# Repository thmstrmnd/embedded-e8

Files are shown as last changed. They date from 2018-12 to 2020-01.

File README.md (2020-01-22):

## Embedded E8

**An open source IoT hardware integration project that extends the capabilities of ESP8266 with components that are readily available in the market. As a result, fast prototyping and independent development is achieved.**

## Table of Contents
1. [Mission](#mission)
2. [General](#general) 
3. [Development Principles](#devprinciples)
4. [Bill of Materials](#bom)
5. [Software Tools](#tools)
6. [Connection Diagram](#connection)
7. [Microcontroller Setup and Code Upload](#setup)
8. [Final Assembly and Quick Reference](#final)
9. [Get Started](#start)
10. [Fork, Clone, then Contribute](#fork-clone-contribute)
11. [License](#license)

## Mission 

The mission of this project is to be a gateway of IoT education for the young, enthusiasts or professionals and to accelerate adoption of the IoT technology in the Philippines in private and business sectors to improve productivity.

## General 

ESP8266 is an impressive microcontroller because of its low cost and small form factor making IoT truly possible to be democratized. However, there are two major challenges of using ESP8266. The first one is lack of analog to digital (ADC) pins, hence by default only one sensor can be used. The second one is it's base voltage 3.3 Volts is not enough to trigger relays. Though there are sensors and relays that are rated 3.3V, they are not commonly available in the market. The most common ones are rated 5V. It is the intention of this project to solve these problems consolidate it into one integrated solution. 

We will also focus on a comprehensive documentation so that majority of the users will easily comprehend the technical aspects. This documentation is expected to be updated frequently. 

There will be 2 types of build. First, the breadboard version and second, the prototyping PCB version. Take note that we will not design nor etch a PCB board. 

The sequel of this project is called Cloud-E8 where you can now hook this up on the web. You can track your sensor data realtime, control your devices in the field and save these data on a database. 

## Development Principles 

Three main principles of this build: 
1. Easy to understand
2. Modular build
3. Affordable costs 

With these three development principles, the barrier to entry will drop. 

The build is modularized into 4 parts:
1. The microcontroller and the safety bus
2. The 5v-3.3V input/output pins
3. The Analog Pins for sensors 
4. The digital outputs and PWMs 

## Bill of Materials 

### For Breadboard Setup

1. WeMos D1 Mini | Qty 1 | https://wiki.wemos.cc/products:d1:d1_mini
2. Multiplexer | Qty 1 | https://learn.sparkfun.com/tutorials/multiplexer-breakout-hookup-guide
3. Level Converter | Qty 1 | https://learn.sparkfun.com/tutorials/bi-directional-logic-level-converter-hookup-guide
4. ULN2003 or ULN2004APG | Qty 1 | https://www.mouser.com/ds/2/408/ULN2004APG_datasheet_en_20101203-1135705.pdf
5. Half-sized Breadboard | Qty 3 | 
6. 1N4001 Diode | Qty 9 |  
7. Terminal Blocks | Qty 7 Pairs |

All these components are available locally. You can buy them in Lazada as well. 

## Software Tools 
1. Arduino IDE (Free) - for writing and uploading ESP codes
2. DraftSight (Free) - for drawing schematics
3. Linux Mint (Free) - desktop OS

## Connection Diagram 
Now you can start wiring components. Follow this [link](https://github.com/IoTPH/Assembly-E8/tree/master/ConnectionDiagram) for your guide. 

## Microcontroller Setup and Code Upload 
1. Download Arduino IDE: https://www.arduino.cc/en/Main/Software
2. Open the IDE and click: File -> Preferences -> Additional Boards Manager --> Paste this link: https://arduino.esp8266.com/stable/package_esp8266com_index.json
3. Then click: Tools -> Board -> Board Manager -> search ESP8266 Community, then click install
4. Then click again the Tools -> Board -> NodeMCU 1.0 (ESP12E Module)
5. Then click again the Tools -> PORT -> USB0 (or anything that works)
6. The click Sketch -> Upload | Note: This procedure uploads the bare minimum code and checks whether there are potential errors. There are two common errors. The first one is on the PORT setting. Go back to Tools -> PORT then choose the right one. The second one is the admin permission error. For linux users, run this command in your terminal to change the permission: $ sudo chown user path. Where "user" is your machine's username and path is the location of the permission denied folder.
7. At this point, you can now start building your projects and prototypes. Here are the sample code [sketches](https://github.com/IoTPH/Assembly-E8/tree/master/WorkableCodeSketches). 

## Final Assembly and Quick Reference 

### Connection Diagram
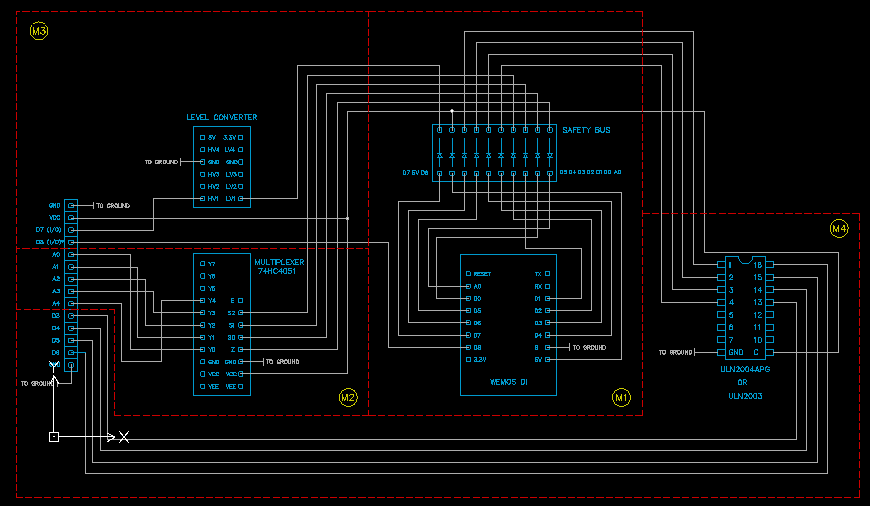
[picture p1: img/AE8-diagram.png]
Connection Diagram


### Breadboard Layout
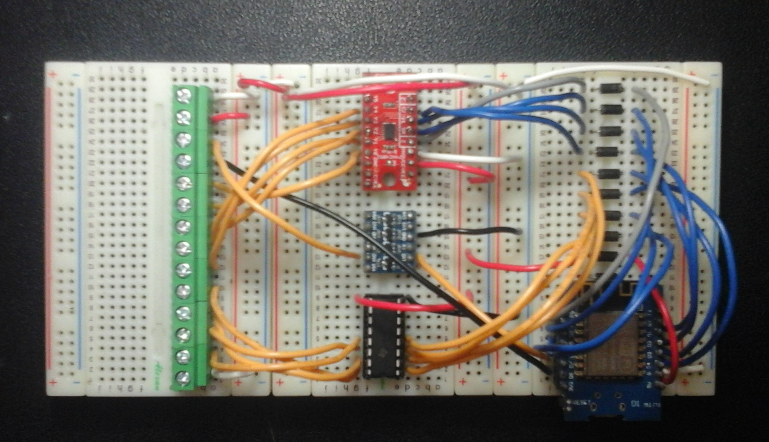
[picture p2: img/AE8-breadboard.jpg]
Breadboard Layout


## Get Started 

#### M1: ESP8266 Module 
* Upload the bare minimum code from the Arduino IDE. If there are errors, check whether you have chosen the right port, have admin access or have properly configured the Arduino IDE for ESP8266. 

#### M2: Multiplexer Module
* The multiplexer extends the analog to digital conversion (ADC) to 5. Hence, you can place up to 5 analog sensors simultaneously. Upload the code [ADConversion.ino](https://github.com/IoTPH/Assembly-E8/tree/master/WorkableCodeSketches) to ESP8266. Connect at least 2 analog sensors, then fire up the serial monitor and check whether it reads the values.

#### M3: Level Conversion Module
* Hookup an ultrasonic sensor HC-SR04 with its supply terminals across VCC and GND while its trigger pin at D7 (voltage level converted) and the echo pin is at D8. Upload the code [UltrasonicSensor.ino](https://github.com/IoTPH/Assembly-E8/tree/master/WorkableCodeSketches) to ESP8266. Fire up the serial monitor and check whether it reads the values.

#### M4: Transistor Array Module
* Connect a relay with its terminal at VCC and GND while its trigger leg at D3, D4, D5 or D6 pins. Upload the code [DigitalOutput.ino](https://github.com/IoTPH/Assembly-E8/tree/master/WorkableCodeSketches) to ESP8266. Check if it triggers the relay.

## Fork, Clone, then Contribute 

This project needs your help. You can voluntarily help us improve the design of the software and hardware. In order for you to do that, you need to do the following:  

### Fork  
You need to *fork* -- create a copy, this repository in your personal GitHub account.  

### Clone
Then, you need to *clone* -- create a local copy, it into your machine.  

### Contribute
Finally, you can start *hacking* -- , it and eventually create a pull request.  

## License: <a id="license"> MIT</a>

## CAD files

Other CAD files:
ConnectionDiagram/AE8.dwg

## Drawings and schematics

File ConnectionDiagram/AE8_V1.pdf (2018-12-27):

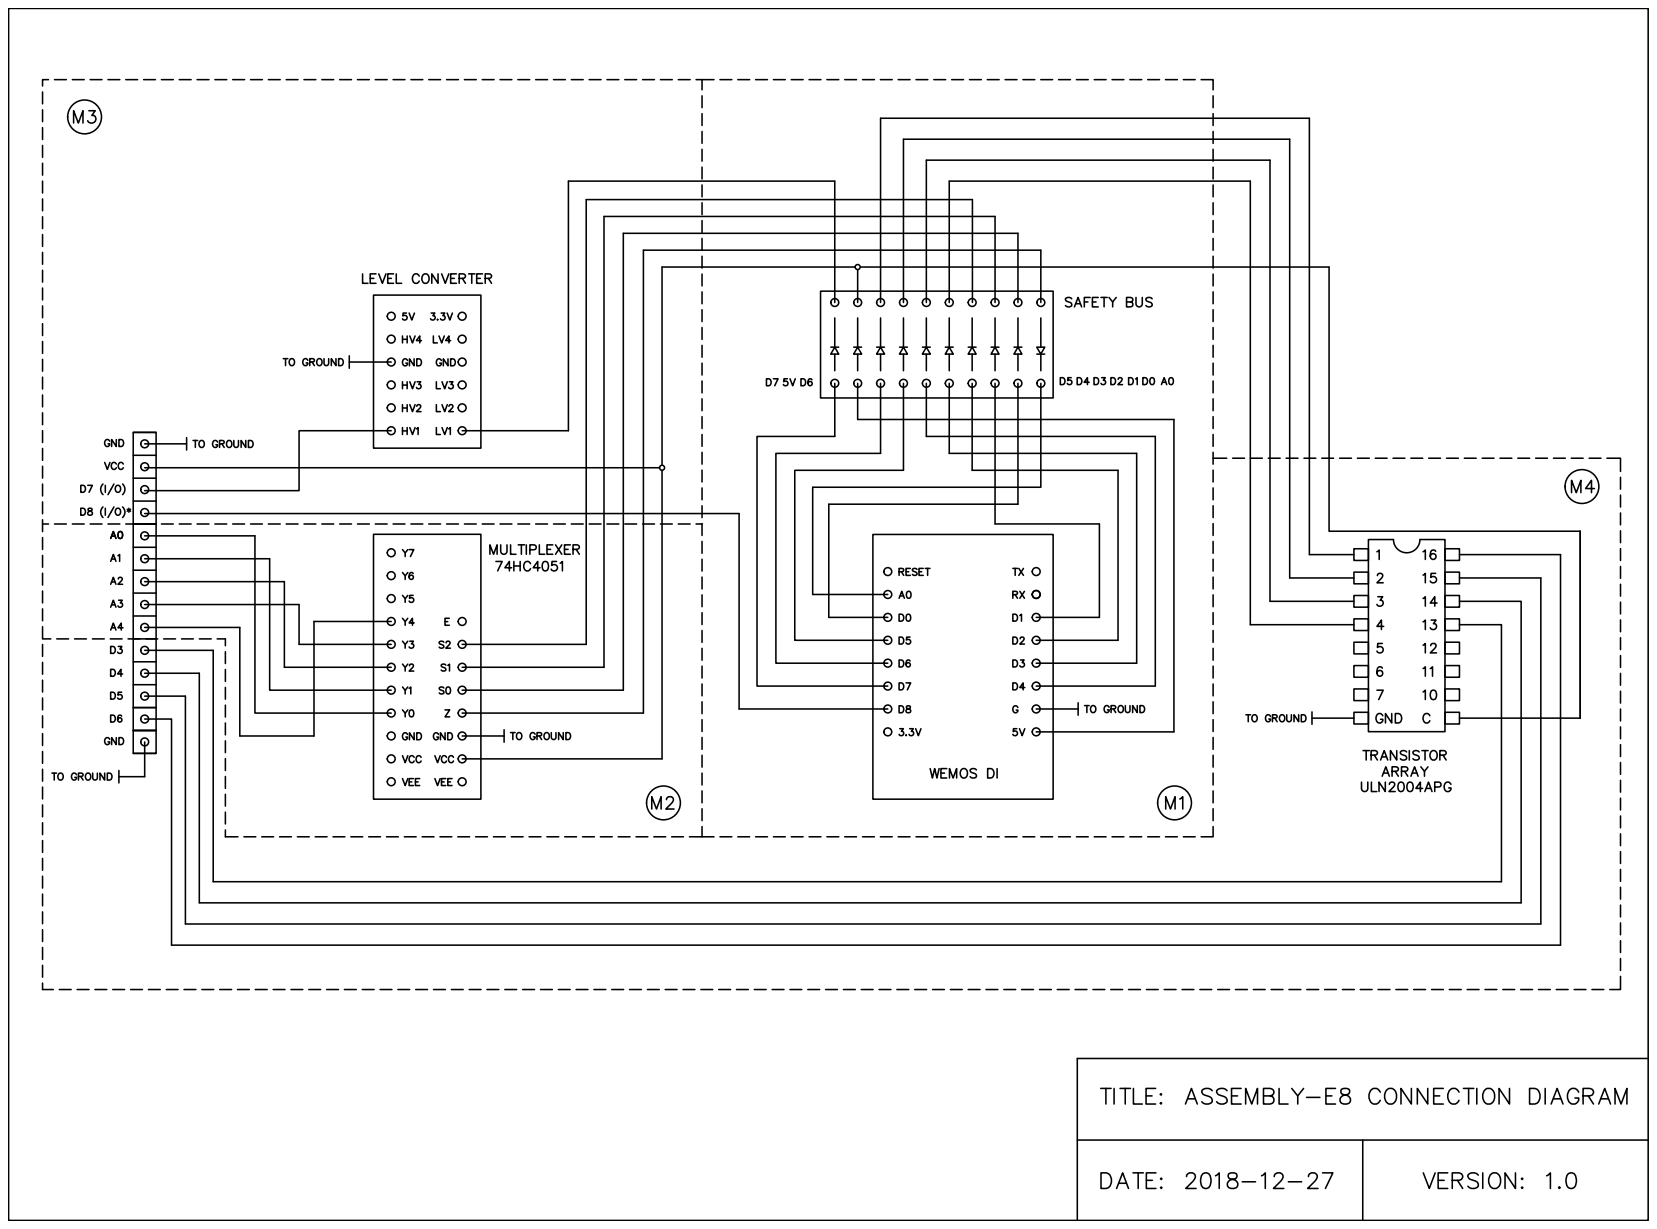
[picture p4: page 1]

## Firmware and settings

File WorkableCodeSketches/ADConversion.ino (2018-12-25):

/* 5 ANALOG SENSORS */
 
int pinOut00 = D0;
int pinOut01 = D1;
int pinOut02 = D2;
int pinOut03 = D3;
int pinOut04 = D4;

int pinInA0 = A0;
int valueInA0 = 0;
int valueInA1 = 0;
int valueInA2 = 0;
int valueInA3 = 0;
int valueInA4 = 0;

void setup() {                
  Serial.begin(9600);
  
  pinMode(pinOut00, OUTPUT);                    
  pinMode(pinOut01, OUTPUT);                    
  pinMode(pinOut02, OUTPUT);
  pinMode(pinOut03, OUTPUT);
  pinMode(pinOut04, OUTPUT);
  pinMode(pinOut05, OUTPUT);
  
  pinMode(pinInA0, INPUT);                      // Setting analog pin A0 to input    
}

void loop() {
  
  digitalWrite(pinOut04, HIGH);                  // Power Indicator
  delay(1000);                                   // Stabilizer

  digitalWrite(pinOut00, LOW);                   // Y0
  digitalWrite(pinOut01, LOW);
  digitalWrite(pinOut02, LOW);
  delay(250);
    valueInA0 = analogRead(pinInA0);             // Sensing voltage input in pin A0 and converting to integer values (0 - 1023)
    Serial.print("A0 = ");                       // Label the ouput 
    Serial.println (valueInA0);
    delay(750);
  
  digitalWrite(pinOut00, HIGH);                  // Y1
  digitalWrite(pinOut01, LOW);
  digitalWrite(pinOut02, LOW);
  delay(250);
    valueInA1 = analogRead(pinInA0);             // Sensing voltage input in pin A0 and converting to integer values (0 - 1023)
    Serial.print("A1 = ");                       // Label the ouput 
    Serial.println (valueInA1);
    delay(750);

  digitalWrite(pinOut00, LOW);                   // Y2
  digitalWrite(pinOut01, HIGH);
  digitalWrite(pinOut02, LOW);
  delay(250);
    valueInA2 = analogRead(pinInA0);             // Sensing voltage input in pin A0 and converting to integer values (0 - 1023)
    Serial.print("A2 = ");                       // Label the ouput 
    Serial.println (valueInA2);
    delay(750); 

  digitalWrite(pinOut00, HIGH);                   // Y3
  digitalWrite(pinOut01, HIGH);
  digitalWrite(pinOut02, LOW);
  delay(250);
    valueInA3 = analogRead(pinInA0);             // Sensing voltage input in pin A0 and converting to integer values (0 - 1023)
    Serial.print("A3 = ");                       // Label the ouput 
    Serial.println (valueInA3);
    delay(750); 

 digitalWrite(pinOut00, LOW);                   // Y4
  digitalWrite(pinOut01, LOW);
  digitalWrite(pinOut02, HIGH);
  delay(250);
    valueInA4 = analogRead(pinInA0);             // Sensing voltage input in pin A0 and converting to integer values (0 - 1023)
    Serial.print("A4 = ");                       // Label the ouput 
    Serial.println (valueInA4);
    delay(750);  
    
}

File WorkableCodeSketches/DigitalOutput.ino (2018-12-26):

int pinOutD3 = D3;                              // Declaring pins to a variable
int pinOutD4 = D4;
int pinOutD5 = D5;
int pinOutD6 = D6;                               
                            

void setup() {                
  Serial.begin(9600);               
  
  pinMode(pinOutD3, OUTPUT);                     // Setting Digital I/O pins as output 
  pinMode(pinOutD4, OUTPUT);                     
  pinMode(pinOutD5, OUTPUT); 
  pinMode(pinOutD6, OUTPUT);   
}

void loop() {    
  
  digitalWrite(pinOutD3, HIGH);                  // Setting Pin D0 On
  digitalWrite(pinOutD4, HIGH);  
  digitalWrite(pinOutD5, HIGH);                  // Setting Pin D1 On
  digitalWrite(pinOutD5, HIGH);
  delay(100);
     
}
  
  

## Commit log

2018-12-09 Add Wemos D1 and Level Converter
    [AE8.dwg]
2018-12-09 Add other components
    [AE8.dwg]
2018-12-10 Added materials
2018-12-12 Improve schematics
    [AE8.dwg]
2018-12-14 Added safety bus
    [AE8.dwg]
2018-12-19 Schematics update
    [AE8.dwg]
2018-12-20 Schematics updated
    [AE8.dwg]
2018-12-22 Module 2 Tested
    [AE8.dwg]
2018-12-25 Module 3 Tested
    [AE8.dwg]
2018-12-27 Added photos
    [AE8.dwg]
